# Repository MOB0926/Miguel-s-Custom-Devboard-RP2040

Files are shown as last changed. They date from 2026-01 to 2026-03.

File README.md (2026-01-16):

# Miguel-s-Custom-Devboard-RP2040
I started this project as a way to practice and learn some more about pcb design. This board is not perfect as it is my second pcb and my first devboard.
    
# Schematic Design
    
I followed the [Custom Devboard Guided Project](https://blueprint.hackclub.com/starter-projects/devboard) by [Kai Pereira](https://github.com/KaiPereira/build-a-devboard) so it was not my design but I did rout the PCB myself an added and LED.
     
The designs and components are directly from the guide but the LED I added once I realized how empty the board was at the pcb design section.
    
Components:
- RP 2040
- LED (SK6812-mini-e)   This is not in KICAD lib, I had to use [Master Lib](https://github.com/ebastler/marbastlib)
- USB-C-2.0
- Voltage regulator (MCP1700T-3302E/TT)
- Crystal Ocilater (12mhz)
- I/O (1x20)x2 (1x3)x1
- Flash Memory/Storage (W25Q16JVZPIQ) (16-Mbi)
     

     
# PCB Design
     
The board dimensions and I/O location are exact from the guide but the rest I ended up moving around to fit my routing. The LED I placed in the very empty bottom of the board above the 1x3 pins.
         
I routed the USB first then the Flash, followed by the crystal ocilator. Once the important connections were made I connected the I/O and LED, lastly I set up the ground pour and fixed any errors the ERC flaged.
         

      

       
# Prep For Manufacturing
         
Once I was sure I had finished the board I downloaded the necessary design files from KICAD (.gbr , BOM , CPL) I edited the BOM and CPL formats to fit JLCPCB and uploaded my design.
      
Once the files were uploaded, I chose the correct settings for my design and whent on to choosing what parts JLCPCB would buy and install for me.
          
ALL basic components I selected and most Extended components as they are far to complicated to solder myself but the I/O pins and LED I will add myself to save A LOT of money. (Almost 30 dollars)
      
I actually made an error originaly where my board was set up as "Standard PCBA" not "Economic PCBA" which is why I had to place the LED myself and why I saved $30.
        

         

          

           

          
# V1 vs V2
          
Honestly they are not too different but V2 was a complete restart for the pcb routing and component placement as V1 was full of errors that were easier to re-do than fix.
       
# BOM
    
- PCB ~ $39.36 [JLCPCB](https://jlcpcb.com/) (For 5 pcbs / 2 pcba)
- I/O Pins ~ $1.26 + Shipping [AliExpress](https://www.aliexpress.us/item/3256805070463808.html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) (For 10 1x40 Breakeable 2.54mm Male Pins)
- LED (SK6812mini-e)(3mA) ~ $3.51 + Shipping [AliExpress]([https://www.aliexpress.us/item/3256806781745425.html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](https://www.aliexpress.us/item/3256807677321116.html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)) (For 100) (Only need one but this is cheaper because of choice shipping than getting a 10pc)
- Total ~ $47
    
# THE END
     
So yeah thats it really
    
I spent about 19-20 hours on this. I learnt A LOT about Schematic/PCB design on KICAD specificaly. I also learnt how to get a project to manufacturing (Which I cant wait to get my first Devboard design to play with)
     
I do not plan to return to this project, I will probably at some point in the near future make another board but with a more specific use and maybe a diferent MCU so I can get more experience

# Thanks

- Myself (For all the time I put into this)
- [Kai Pereira](https://kaipereira.com/) (For the Guide)
- [HackClub](https://hackclub.com/) / [Blueprint](https://blueprint.hackclub.com/home) (For the opportunity to do a project like this)
- You (For reading this)

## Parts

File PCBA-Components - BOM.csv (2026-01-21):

Comment | Designator | Footprint | JLCPCB Part #
330 | R8 | R_0402_1005Metric | C25104
1uF | C1,C10 | C_0402_1005Metric | C52923
MCP1700x-330xxTT | U2 | SOT-23 | C39051
33pF | C15,C16 | C_0402_1005Metric | C1562
1K | R6,R5 | R_0402_1005Metric | C11702
5.1K | R1,R2 | R_0402_1005Metric | C25905
12MHz | Y1 | Crystal_SMD_3225-4Pin_3.2x2.5mm | C9002
10uF | C14,C13 | C_0603_1608Metric | C19702
RP2040 | U1 | QFN-56-1EP_7x7mm_P0.4mm_EP3.2x3.2mm | C2040
0.1uF | C17,C7,C8,C2,C12,C9,C11,C5,C3,C4,C6,C18 | C_0402_1005Metric | C1525
W25Q16JVZPIQTR | U3 | Winbond_USON-8-1EP_3x2mm_P0.5mm_EP0.2x1.6mm | C2843335
10K | R7 | R_0402_1005Metric | C25744
USB_C_Receptacle_USB2.0_14P | J1 | USB_C_Receptacle_HRO_TYPE-C-31-M-12 | C165948
27 | R3,R4 | R_0402_1005Metric | C25100
SW_Push | SW1 | SW_Push_SPST_NO_Alps_SKRK | C720477

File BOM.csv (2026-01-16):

Item | Price (incl: shipping) | Qty | Vendor
PCB | $4 | x5 | JLCPCB
PCBA | $35.36 | x2 | JLCPCB
SK6812mini-e | $4.51 | x100 | AliExpress
01x40 Pin Headers | $2.26 | x10 | AliExpress
Total | $46.13

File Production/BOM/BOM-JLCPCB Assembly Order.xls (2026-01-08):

JLCPCB BOM Tool - BOM Matching
BOM name：BOM-JLCPCB Assembly Order.xlsx |  |  | Download Time：2026-01-08 03:55:06 |  |  |  | * Our matching results are updated in real-time, but stock and prices may change. If it's been over 24 hours, please re-match before placing your order.
PCB Assembled Qty：5 |  |  | Est. Total Price：13.4184
Your BOM |  |  |  |  | Matched Parts |  |  |  |  |  |  | Order Information
Top Designator | Bottom Designator | Comment | Footprint | JLCPCB Part # | Matches | Part # | Manufacturer | Footprint | Description | Category | Warning | JLCPCB Part # | Product link | Lib Type | Qty | Source | Total Price ($)
C1,C10 |  | 1uF | C_0402_1005Metric |  | Select by Customer | CL05A105KA5NQNC | Samsung Electro-Mechanics | 0402 | 1uF 25V X5R ±10% 0402 Multilayer Ceramic Capacitors MLCC - SMD/SMT ROHS | Multilayer Ceramic Capacitors MLCC - SMD/SMT |  | C52923 | https://jlcpcb.com/partdetail/53938-CL05A105KA5NQNC/C52923 | Basic | 20 | 20 JLCPCB | 0.06
C14,C13 |  | 10uF | C_0603_1608Metric |  | Select by Customer | CL10A106KP8NNNC | Samsung Electro-Mechanics | 0603 | 10V 10uF X5R ±10% 0603 Multilayer Ceramic Capacitors MLCC - SMD/SMT ROHS | Multilayer Ceramic Capacitors MLCC - SMD/SMT |  | C19702 | https://jlcpcb.com/partdetail/20411-CL10A106KP8NNNC/C19702 | Basic | 20 | 20 JLCPCB | 0.116
C15,C16 |  | 33pF | C_0402_1005Metric |  | Select by Customer | 0402CG330J500NT | FH (Guangdong Fenghua Advanced Tech) | 0402 | 33pF 50V C0G ±5% 0402 Multilayer Ceramic Capacitors MLCC - SMD/SMT ROHS | Multilayer Ceramic Capacitors MLCC - SMD/SMT |  | C1562 | https://jlcpcb.com/partdetail/1914-0402CG330J500NT/C1562 | Basic | 20 | 20 JLCPCB | 0.022
C17,C7,C8,C2,C12,C9,C11,C5,C3,C4,C6,C18 |  | 0.1uF | C_0402_1005Metric |  | Select by Customer | CL05B104KO5NNNC | Samsung Electro-Mechanics | 0402 | 100nF 16V X7R ±10% 0402 Multilayer Ceramic Capacitors MLCC - SMD/SMT ROHS | Multilayer Ceramic Capacitors MLCC - SMD/SMT | 1.The comment (CL05B104KO5NNNC) of this part does not match the one (0.1uF) provided in your BOM. Please confirm; | C1525 | https://jlcpcb.com/partdetail/1877-CL05B104KO5NNNC/C1525 | Basic | 70 | 70 JLCPCB | 0.084
J1 |  | USB_C_Receptacle_USB2.0_14P | USB_C_Receptacle_HRO_TYPE-C-31-M-12 |  | Select by Customer | TYPE-C-31-M-12 | Korean Hroparts Elec | SMD | -30℃~+80℃ 1 10,000 cycles 16P 20V 5A 7.35mm Female Surface Mount, Right Angle Type-C SMD USB Connectors ROHS | USB Connectors |  | C165948 | https://jlcpcb.com/partdetail/Korean_HropartsElec-TYPE_C_31_M12/C165948 | Extended | 5 | 5 JLCPCB | 0.8825
J3,J2 |  | Conn_01x20 | PinHeader_1x20_P2.54mm_Vertical |  | Select by Customer | KH-1.27PH180-1X20P-L7.2 | Shenzhen Kinghelm Elec | 插件,P=1.27mm | -40℃~+105℃ 1 1.27mm 1A 1mm 1x20P 2.3mm 20P 3.9mm Pin Header Through Hole Plugin,P=1.27mm Pin Headers ROHS | Pin Headers |  | C2938409 | https://jlcpcb.com/partdetail/3294789-KH_1_27PH180_1X20P_L72/C2938409 | Extended | 0 | 0 JLCPCB | 0
J4 |  | Conn_01x03 | PinHeader_1x03_P2.54mm_Vertical |  | Select by Customer | 2.54-1*3P针 | BOOMELE(Boom Precision Elec) | 插件,P=2.54mm | -40℃~+105℃ 1 1x3P 2.54mm 2.5mm 3A 3P 3mm 6mm Black Brass Gold Pin Header Through Hole Plugin,P=2.54mm Pin Headers ROHS | Pin Headers |  | C49257 | https://jlcpcb.com/partdetail/50265-2_54_1_3P/C49257 | Extended | 0 | 0 JLCPCB | 0
LED1 |  | SK6812MINI-E | LED_6028R |  | Select by Customer | SK6812MINI-E | OPSCO Optoelectronics | SMD | -40℃~+85℃ 0.6mA 1.78mm 120° 1kHz 2.8mm 2000V 3.2mm 3.7V~5.5V 800Kbit/s G:815mcd~1275mcd R:620nm~625nm Semi-transparent lens SMD RGB LEDs(Built-in IC) ROHS | RGB LEDs(Built-In IC) |  | C5149201 | https://jlcpcb.com/partdetail/OPSCOOptoelectronics-SK6812MINIE/C5149201 | Extended | 7 | 7 JLCPCB | 0.6034
R1,R2 |  | 5.1K | R_0402_1005Metric |  | Select by Customer | 0402WGF5101TCE | UNI-ROYAL(Uniroyal Elec) | 0402 | -55℃~+155℃ 5.1kΩ 50V 62.5mW Thick Film Resistor ±1% ±100ppm/℃ 0402 Chip Resistor - Surface Mount ROHS | Chip Resistor - Surface Mount |  | C25905 | https://jlcpcb.com/partdetail/26648-0402WGF5101TCE/C25905 | Basic | 20 | 20 JLCPCB | 0.012
R3,R4 |  | 27 | R_0402_1005Metric |  | Select by Customer | 0402WGF270JTCE | UNI-ROYAL(Uniroyal Elec) | 0402 | -55℃~+155℃ 27Ω 50V 62.5mW Thick Film Resistor ±1% ±100ppm/℃ 0402 Chip Resistor - Surface Mount ROHS | Chip Resistor - Surface Mount | 1.The comment (0402WGF270JTCE) of this part does not match the one (27) provided in your BOM. Please confirm; | C25100 | https://jlcpcb.com/partdetail/25843-0402WGF270JTCE/C25100 | Extended | 22 | 22 JLCPCB | 0.0132
R6,R5 |  | 1K | R_0402_1005Metric |  | Select by Customer | 0402WGF1001TCE | UNI-ROYAL(Uniroyal Elec) | 0402 | -55℃~+155℃ 1kΩ 50V 62.5mW Thick Film Resistor ±1% ±100ppm/℃ 0402 Chip Resistor - Surface Mount ROHS | Chip Resistor - Surface Mount | 1.The comment (0402WGF1001TCE) of this part does not match the one (1K) provided in your BOM. Please confirm; | C11702 | https://jlcpcb.com/partdetail/12256-0402WGF1001TCE/C11702 | Basic | 20 | 20 JLCPCB | 0.012
R7 |  | 10K | R_0402_1005Metric |  | Select by Customer | 0402WGF1002TCE | UNI-ROYAL(Uniroyal Elec) | 0402 | -55℃~+155℃ 10kΩ 50V 62.5mW Thick Film Resistor ±1% ±100ppm/℃ 0402 Chip Resistor - Surface Mount ROHS | Chip Resistor - Surface Mount | 1.The comment (0402WGF1002TCE) of this part does not match the one (10K) provided in your BOM. Please confirm; | C25744 | https://jlcpcb.com/partdetail/26487-0402WGF1002TCE/C25744 | Basic | 20 | 20 JLCPCB | 0.012
R8 |  | 330 | R_0402_1005Metric |  | Select by Customer | 0402WGF3300TCE | UNI-ROYAL(Uniroyal Elec) | 0402 | -55℃~+155℃ 330Ω 50V 62.5mW Thick Film Resistor ±1% ±100ppm/℃ 0402 Chip Resistor - Surface Mount ROHS | Chip Resistor - Surface Mount | 1.The comment (0402WGF3300TCE) of this part does not match the one (330) provided in your BOM. Please confirm; | C25104 | https://jlcpcb.com/partdetail/25847-0402WGF3300TCE/C25104 | Basic | 20 | 20 JLCPCB | 0.014
SW1 |  | SW_Push | SW_Push_SPST_NO_Alps_SKRK |  | Select by Customer | TS-1088-AR02016 | XUNPU | SMD,4x3mm | -30℃~+80℃ 1.6N 100,000 Cycles 12V 2mm 3mm 4mm 50mA Black Round Button SMD(SMT) Tab SPST Surface Mount,Vertical Without Bracket SMD,4x3mm Tactile Switches ROHS | Tactile Switches |  | C720477 | https://jlcpcb.com/partdetail/XUNPU-TS_1088AR02016/C720477 | Basic | 9 | 9 JLCPCB | 0.3987
U1 |  | RP2040 | QFN-56-1EP_7x7mm_P0.4mm_EP3.2x3.2mm |  | Select by Customer | RP2040 | Raspberry Pi | LQFN-56(7x7) | 12bit 133MHz 30 LQFN-56(7x7) Microcontrollers (MCU/MPU/SOC) ROHS | Microcontrollers (MCU/MPU/SOC) |  | C2040 | https://jlcpcb.com/partdetail/RaspberryPi-RP2040/C2040 | Extended | 5 | 5 JLCPCB | 4.7745
U2 |  | MCP1700x-330xxTT | SOT-23 |  | Select by Customer | MCP1700T-3302E/TT | Microchip Tech | SOT-23 | -40℃~+125℃@(Tj) 1 1.6uA 178mV@(250mA) 250mA 3.3V 44dB@(100Hz) 6V Fixed Over Temperature Protection Positive SOT-23 Voltage Regulators - Linear, Low Drop Out (LDO) Regulators ROHS | Voltage Regulators - Linear, Low Drop Out (LDO) Regulators |  | C39051 | https://jlcpcb.com/partdetail/MicrochipTech-MCP1700T_3302ETT/C39051 | Extended | 5 | 5 JLCPCB | 1.7865
U3 |  | W25Q16JVZPIQTR | Winbond_USON-8-1EP_3x2mm_P0.5mm_EP0.2x1.6mm |  | Select by Customer | W25Q16JVUXIQ | Winbond Elec | USON-8-EP(2x3) | -40℃~+85℃ 100,000 Cycles 10uA 133MHz 16Mbit 2.7V~3.6V 20 Years 3ms SPI USON-8-EP(2x3) NOR FLASH ROHS | NOR FLASH | 1.The comment (W25Q16JVUXIQ) of this part does not match the one (W25Q16JVZPIQTR) provided in your BOM. Please confirm; | C2843335 | https://jlcpcb.com/partdetail/WinbondElec-W25Q16JVUXIQ/C2843335 | Extended | 5 | 5 JLCPCB | 4.0165
Y1 |  | 12MHz | Crystal_SMD_3225-4Pin_3.2x2.5mm |  | Select by Customer | X322512MSB4SI | YXC Crystal Oscillators | SMD3225-4P | -40℃~+85℃ 12MHz 20pF Crystal Oscillator ±10ppm ±20ppm SMD3225-4P Crystals ROHS | Crystals |  | C9002 | https://jlcpcb.com/partdetail/YXC_CrystalOscillators-X322512MSB4SI/C9002 | Basic | 9 | 9 JLCPCB | 0.6111

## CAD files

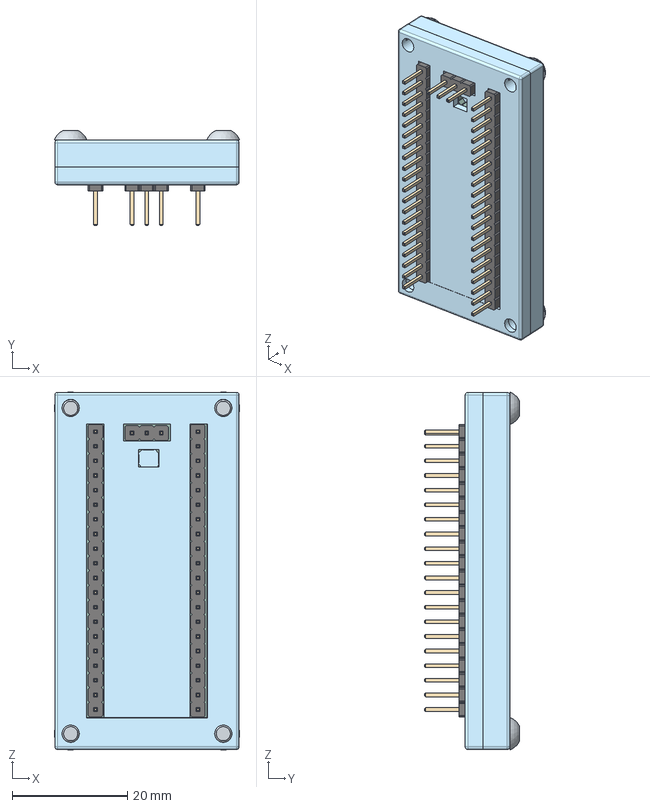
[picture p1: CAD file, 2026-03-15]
3D-Render/3D-Model.step
32.2 x 16.5 x 62.2 mm
R_0402_1005Metric_3
C_0402_1005Metric_11
PinHeader_1x20_P2.54mm_Vertical_1
C_0402_1005Metric_10
R_0402_1005Metric_1
C_0402_1005Metric_9
C_0402_1005Metric_5
C_0402_1005Metric_12
PinHeader_1x20_P2.54mm_Vertical
Crystal_SMD_3225-4Pin_3.2x2.5mm
QFN-56-1EP_7x7mm_P0.4mm_EP3.2x3.2mm
C_0603_1608Metric
R_0402_1005Metric_2
R_0402_1005Metric_7
Winbond_USON-8-1EP_3x2mm_P0.5mm_EP0.2x1.6mm
R_0402_1005Metric
SOT-23
C_0402_1005Metric_14
C_0402_1005Metric_1
PinHeader_1x03_P2.54mm_Vertical
Socket button head screw M3x0.5 x 5 x 4
C_0402_1005Metric_6
C_0402_1005Metric_7
C_0402_1005Metric_4
C_0402_1005Metric_15
C_0402_1005Metric_8
C_0402_1005Metric_13
C_0603_1608Metric_1
SW_Push_SPST_NO_Alps_SKRK
C_0402_1005Metric
R_0402_1005Metric_6
R_0402_1005Metric_4
C_0402_1005Metric_2
C_0402_1005Metric_3
R_0402_1005Metric_5

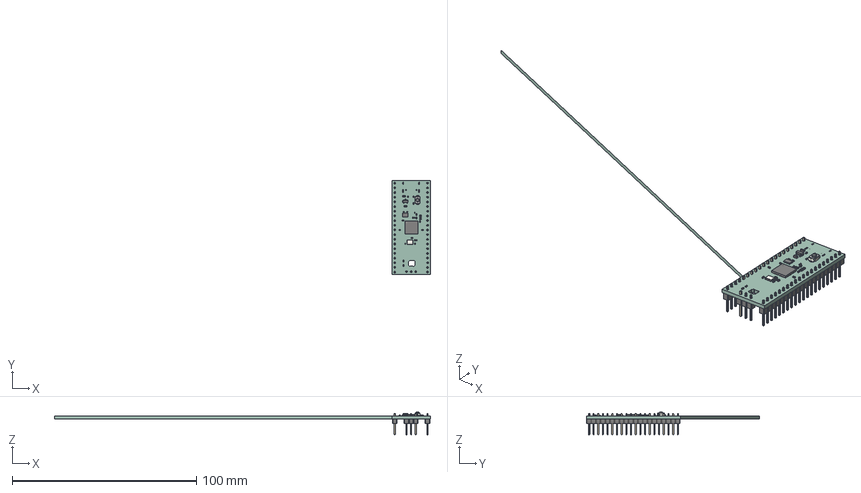
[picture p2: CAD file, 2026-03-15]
PCB/PCB-V2/Miguel's-Custom-Devboard - V2.step
204.0 x 94.0 x 12.2 mm
C_0402_1005Metric x 16
R_0402_1005Metric x 8
QFN-56-1EP_7x7mm_P0.4mm_EP3.2x3.2mm
C_0603_1608Metric x 2
Crystal_SMD_3225-4Pin_3.2x2.5mm
SOT-23
SW_Push_SPST_NO_Alps_SKRK
Winbond_USON-8-1EP_3x2mm_P0.5mm_EP0.2x1.6mm
PinHeader_1x03_P2.54mm_Vertical
PinHeader_1x20_P2.54mm_Vertical x 2
Miguel's-Custom-Devboard - V2_PCB

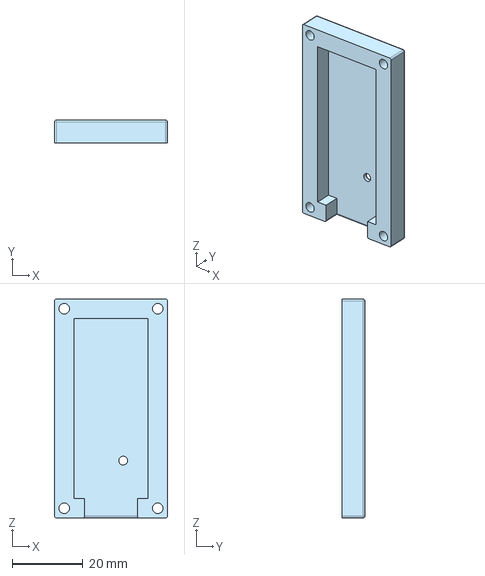
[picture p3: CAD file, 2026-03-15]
3D-Render/Case-Top.step
32.0 x 6.50 x 62.0 mm

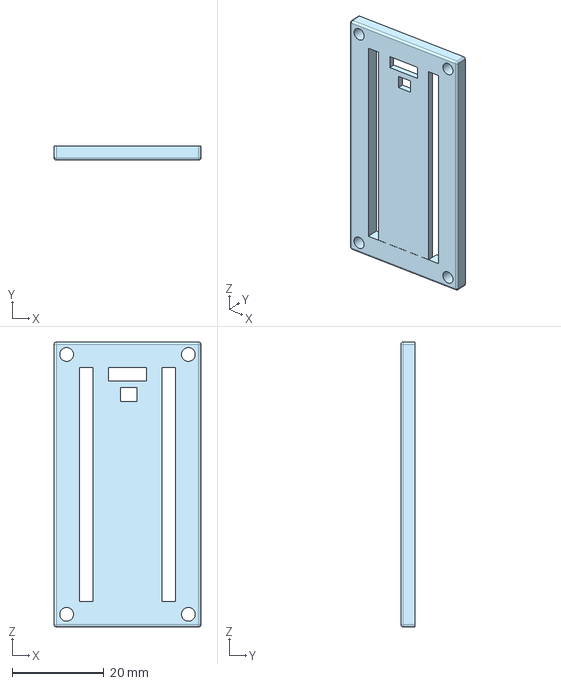
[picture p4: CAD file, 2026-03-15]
3D-Render/Case-Bottom.step
32.0 x 3.10 x 62.0 mm

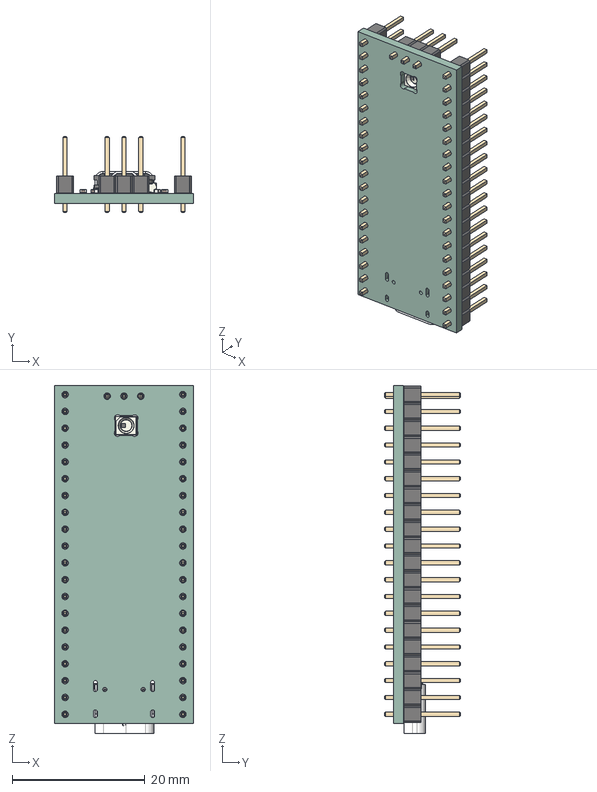
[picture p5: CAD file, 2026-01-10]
3D-Render/Miguel's-Custom-Devboard-RP-2040-3D-Render.step
21.0 x 11.5 x 52.5 mm
USB_type_C_6p x 4
QFN-56-1EP_7x7mm_P0.4mm_EP3.2x3.2mm
R_0402_1005Metric x 8
C_0603_1608Metric x 2
LED_SK6812MINI-E x 5
PinHeader_1x20_P2.54mm_Vertical x 2
C_0402_1005Metric x 16
PinHeader_1x03_P2.54mm_Vertical
Crystal_SMD_3225-4Pin_3.2x2.5mm
Winbond_USON-8-1EP_3x2mm_P0.5mm_EP0.2x1.6mm
SW_Push_SPST_NO_Alps_SKRK
SOT-23

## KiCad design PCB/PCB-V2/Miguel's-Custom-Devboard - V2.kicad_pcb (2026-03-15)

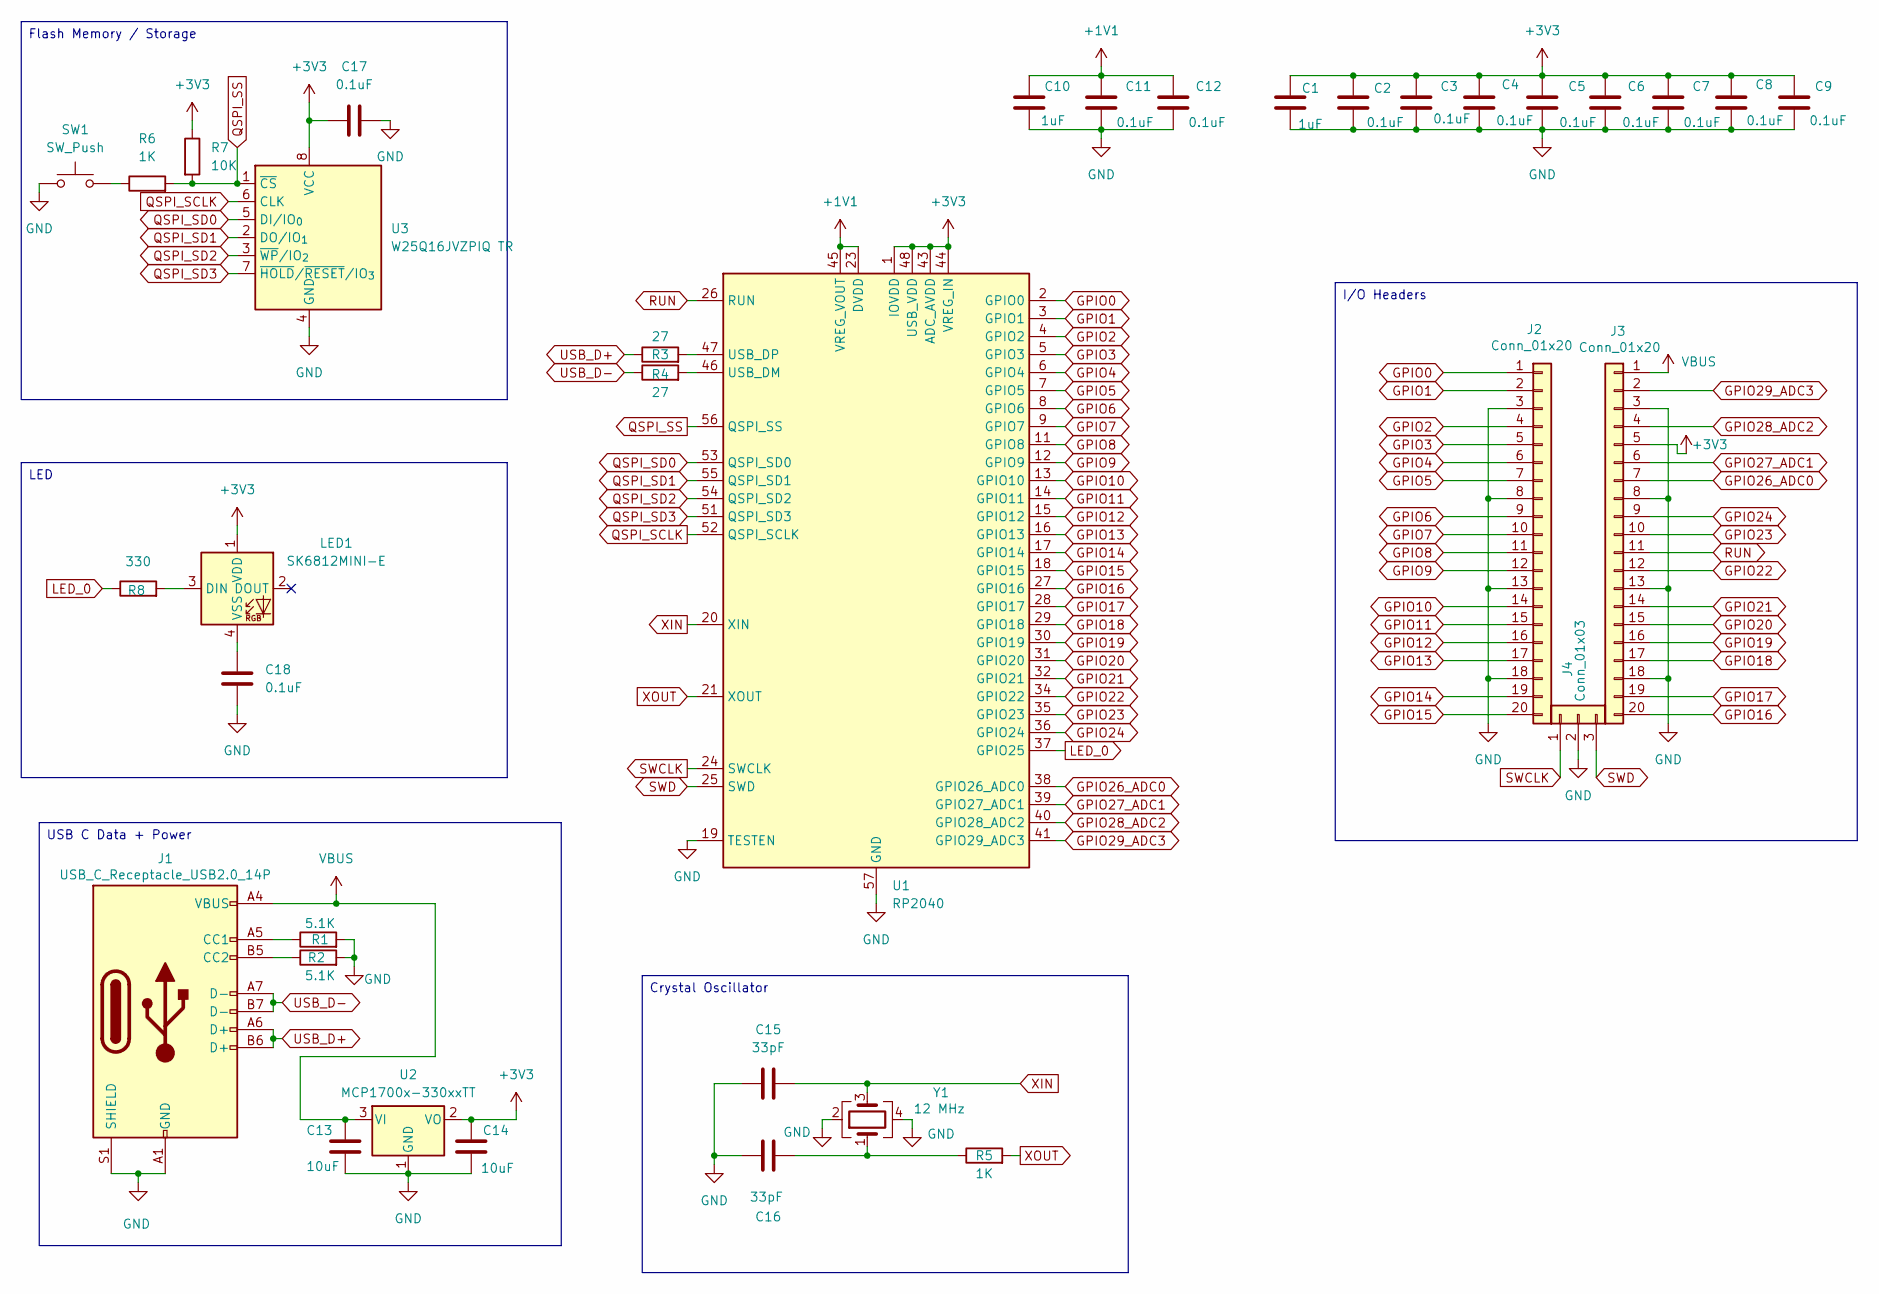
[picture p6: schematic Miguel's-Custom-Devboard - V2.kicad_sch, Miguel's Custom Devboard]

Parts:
C1, C10: 1uF; C_0402_1005Metric
C2, C3, C4, C5, C6, C7, C8, C9, C11, C12, C17, C18: 0.1uF; C_0402_1005Metric
C13, C14: 10uF; C_0603_1608Metric
C15, C16: 33pF; C_0402_1005Metric
J1: USB_C_Receptacle_USB2.0_14P; USB_C_Receptacle_HRO_TYPE-C-31-M-12
J2, J3: Conn_01x20; PinHeader_1x20_P2.54mm_Vertical
J4: Conn_01x03; PinHeader_1x03_P2.54mm_Vertical
LED1: SK6812MINI-E; LED_6028R
R1, R2: 5.1K; R_0402_1005Metric
R3, R4: 27; R_0402_1005Metric
R5, R6: 1K; R_0402_1005Metric
R7: 10K; R_0402_1005Metric
R8: 330; R_0402_1005Metric
SW1: SW_Push; SW_Push_SPST_NO_Alps_SKRK
U1: RP2040; QFN-56-1EP_7x7mm_P0.4mm_EP3.2x3.2mm
U2: MCP1700x-330xxTT; SOT-23
U3: W25Q16JVZPIQ TR; Winbond_USON-8-1EP_3x2mm_P0.5mm_EP0.2x1.6mm
Y1: 12 MHz; Crystal_SMD_3225-4Pin_3.2x2.5mm

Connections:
+1V1: C10.1, C11.1, C12.1, U1.23 (DVDD), U1.45 (VREG_VOUT), U1.50 (DVDD)
+3V3: C1.1, C2.1, C3.1, C4.1, C5.1, C6.1, C7.1, C8.1, C9.1, C14.1, C17.1, J3.5, LED1.1 (VDD), R7.1, U1.1 (IOVDD), U1.10 (IOVDD), U1.22 (IOVDD), U1.33 (IOVDD), U1.42 (IOVDD), U1.43 (ADC_AVDD), U1.44 (VREG_IN), U1.48 (USB_VDD), U1.49 (IOVDD), U2.2 (VO), U3.8 (VCC)
GND: C1.2, C2.2, C3.2, C4.2, C5.2, C6.2, C7.2, C8.2, C9.2, C10.2, C11.2, C12.2, C13.2, C14.2, C15.1, C16.1, C17.2, C18.2, J1.A1 (GND), J1.A12 (GND), J1.B1 (GND), J1.B12 (GND), J1.S1 (SHIELD), J2.3, J2.8, J2.13, J2.18, J3.3, J3.8, J3.13, J3.18, J4.2, R1.2, R2.2, SW1.1, U1.19 (TESTEN), U1.57 (GND), U2.1 (GND), U3.4 (GND), Y1.2, Y1.4
GPIO0: J2.1, U1.2 (GPIO0)
GPIO1: J2.2, U1.3 (GPIO1)
GPIO2: J2.4, U1.4 (GPIO2)
GPIO3: J2.5, U1.5 (GPIO3)
GPIO4: J2.6, U1.6 (GPIO4)
GPIO5: J2.7, U1.7 (GPIO5)
GPIO6: J2.9, U1.8 (GPIO6)
GPIO7: J2.10, U1.9 (GPIO7)
GPIO8: J2.11, U1.11 (GPIO8)
GPIO9: J2.12, U1.12 (GPIO9)
GPIO10: J2.14, U1.13 (GPIO10)
GPIO11: J2.15, U1.14 (GPIO11)
GPIO12: J2.16, U1.15 (GPIO12)
GPIO13: J2.17, U1.16 (GPIO13)
GPIO14: J2.19, U1.17 (GPIO14)
GPIO15: J2.20, U1.18 (GPIO15)
GPIO16: J3.20, U1.27 (GPIO16)
GPIO17: J3.19, U1.28 (GPIO17)
GPIO18: J3.17, U1.29 (GPIO18)
GPIO19: J3.16, U1.30 (GPIO19)
GPIO20: J3.15, U1.31 (GPIO20)
GPIO21: J3.14, U1.32 (GPIO21)
GPIO22: J3.12, U1.34 (GPIO22)
GPIO23: J3.10, U1.35 (GPIO23)
GPIO24: J3.9, U1.36 (GPIO24)
GPIO26_ADC0: J3.7, U1.38 (GPIO26_ADC0)
GPIO27_ADC1: J3.6, U1.39 (GPIO27_ADC1)
GPIO28_ADC2: J3.4, U1.40 (GPIO28_ADC2)
GPIO29_ADC3: J3.2, U1.41 (GPIO29_ADC3)
LED_0: R8.1, U1.37 (GPIO25)
unnamed: C16.2, R5.1, Y1.1
unnamed: J1.A5 (CC1), R1.1
unnamed: J1.B5 (CC2), R2.1
unnamed: LED1.3 (DIN), R8.2
unnamed: C18.1, LED1.4 (VSS)
unnamed: R6.1, SW1.2
unnamed: R4.2, U1.46 (USB_DM)
unnamed: R3.2, U1.47 (USB_DP)
QSPI_SCLK: U1.52 (QSPI_SCLK), U3.6 (CLK)
QSPI_SD0: U1.53 (QSPI_SD0), U3.5 (DI/IO_{0})
QSPI_SD1: U1.55 (QSPI_SD1), U3.2 (DO/IO_{1})
QSPI_SD2: U1.54 (QSPI_SD2), U3.3 (~WP/IO_{2})
QSPI_SD3: U1.51 (QSPI_SD3), U3.7 (~HOLD/~RESET/IO_{3})
QSPI_SS: R6.2, R7.2, U1.56 (QSPI_SS), U3.1 (~CS)
RUN: J3.11, U1.26 (RUN)
SWCLK: J4.1, U1.24 (SWCLK)
SWD: J4.3, U1.25 (SWD)
USB_D+: J1.A6 (D+), J1.B6 (D+), R3.1
USB_D-: J1.A7 (D-), J1.B7 (D-), R4.1
VBUS: C13.1, J1.A4 (VBUS), J1.A9 (VBUS), J1.B4 (VBUS), J1.B9 (VBUS), J3.1, U2.3 (VI)
XIN: C15.2, U1.20 (XIN), Y1.3
XOUT: R5.2, U1.21 (XOUT)

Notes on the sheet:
Crystal Oscillator
Flash Memory / Storage
I/O Headers
USB C Data + Power
LED

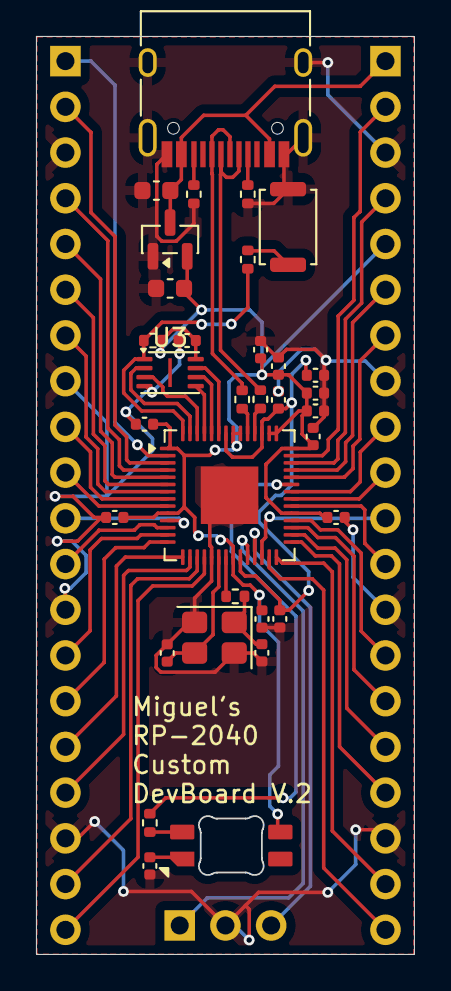
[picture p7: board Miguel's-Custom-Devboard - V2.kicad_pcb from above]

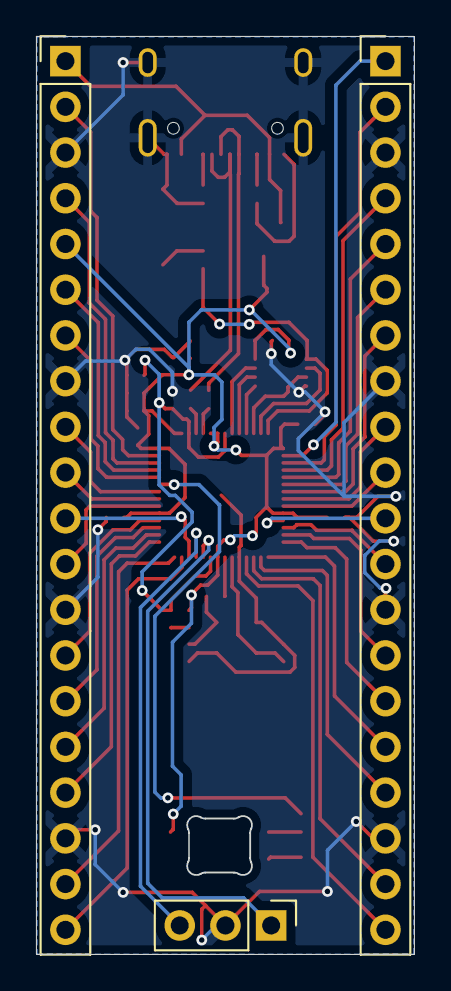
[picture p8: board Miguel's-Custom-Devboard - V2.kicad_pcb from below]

Board: 2 copper layers, 21.0 x 51.0 mm, 36 parts (3 on the bottom side), 55 nets.

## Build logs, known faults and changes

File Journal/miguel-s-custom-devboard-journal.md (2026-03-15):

<!--
  This journal is auto generated by Hack Club Blueprint.
-->

# 12/29/2025 - Created Schematic  

_Time spent: 3.5h_  

I created a File for my project and added a PCB file inside where I will be housing my KiCad files for the project.

I then began to add my components into my schematic. For this I followed the guide on what I needed and how I connected it all. 

Components: 
- RP2040 (MCU)
- Crystal Oscillator (Clock Basicaly)
- Flash Memory (Memory / Storage)
- I/O Headers
- USB_C (For power and data)

After I added everything I ran an ERC (Electrical Rules Check) to make sure there were no errors I did not notice.

imagen

# 12/30/2025 12 AM - Laying out the PCB  

_Time spent: 4.5h_  

Assigned the correct footprints for the components in the schematic footprint editor.

Once the schematic was done I got started on the PCB.

I set the large components in place and most of the capacitors. I then began to rout the high speed connections to get an idea of where to place all other connections.

(I am in PCB hell with these capacitors)

After the highspeed was done I began to connect the capacitors and GPIO pins.

I now must sleep so the rest of the PCB will have to be completed tomorrow.

imagen

# 12/30/2025 4 PM - Continued Routing PCB + Added LED  

_Time spent: 1.5h_  

Finished routing GPIO and noticed the GPIO 25 was unused, so I added an addressable LED (SK6812 Mini)

After that I contiued with the ground but im out of time so I will finish it later.

imagen

imagen

# 12/31/2025 - Finished Routing  

_Time spent: 0.5h_  

I finaly finished all of the unfinished traces, and I technicaly finished my PCB but it has a lot of DRC errors and warnings.

I think the board is very ineficient since it is my first attemt at such a complicated build, so I am tempted to give the PCB a second run now that I am more experienced.

imagen

imagen

# 1/3/2026 - V.2 of PCB  

_Time spent: 3.0h_  

Well I completetly re-routed the PCB in a V.2 doc to fix all of the errors and ineficiensies without completely erasing my work.

This took much longer than it should have but i have been traveling a lot and made the error of not constantly saving a few times.

I also removed most of the silkscreen as it was getting out of hand





# 1/8/2026 5:04 PM - Prepared for Possible Production  

_Time spent: 5.0h_  

I prepared my design for manufacturing in JLCPCB

This took a long time because it is the first time I do this and once I was almost done I realized the LED I had chosen was unavailable and had to choose another one, which meant going back to the schematic and pcb and completely redoing the prep for manufacturing.
   

   

   

   

(WOW THIS IS EXPENSIVE) (Definitely going to have to remove some things to solder myself)  

# 1/8/2026 5:18 PM - A.I. strikes again  

_Time spent: 0.1h_  

I removed any part I had any skill to solder myself but I would only really save like max 8 dollars which is definitely less than what it would cost to buy these components myself plus the risk of damaging anything
   
I guess this one will have to wait due to the A.I. ram/memory crisis making my flash memory cost 4x what it should
   
  

# 1/8/2026 5:34 PM - It was not A.I.  

_Time spent: 0.1h_  

BOOOOOM Figured it out.
I stuck my two braincells together and realized I had it a Standard PCBA not Economic

Changing it cause a slight problem where it would deny me the ability to use economic due to my led but by changing it to a different version and then deselecting it I have succeded in saving myself 30 dollars


  

    


# 1/9/2026 9 PM - Created Repo  

_Time spent: 1.0h_  

I uploaded my design files and jurnal to my repo, and created a readme where I added information and pictures of my work and journey through this project.



# 1/9/2026 10 PM - Finalized Repo + Product Shipped  

_Time spent: 1.0h_  

I checked the guidelines and am pretty sure my project is ready for submission. I completed my repo and finished my BOM

I have now sent my project in for review (I hope I didn't forget anything dumb)





# 1/14/2026 - Updated BOM  

_Time spent: 0.1h_  

Hehehe I forgot to change to only 2 pcba, I never did because JLCPCB was not allowing me to select it in the cart but after some research I just had to go back to edit the pcb settings so I got that resolved

Also my BOM was a little inaccurate so I updated that to reflect the changes





# 1/20/2026 - PCBA - BOM  

_Time spent: 0.1h_  

Added CSV file to Repository containing my PCBA bill of materials from JLCPCB. Whats not included there are the LED and GPIO headers but that's because that I will add myself.

(Ill also add pictures here if that's easier.)



# 1/22/2026 - Grant Approved / Everything Ordered  

_Time spent: 0.5h_  

Got my grant approved a little earlier today, so i have now ordered everything and will be able to get to work in a very long time. (This will actually take like 2-3 weeks so do not expect updates ANY time soon)



  

# 2/11/2026 - Made A Case  

_Time spent: 3.0h_  

I have the boards as of a week or two ago. 

I'm still waiting for the AliExpress order so I made a little case to keep my project safe while I wait.



I made the case for M3 by 5 bolts but they looked monstrous in the CAD so I swapped to M2 for the picture. I only have M3 so i will just have to live with the awkward proportions. 

I'll probably come back to this and make it larger to better fit the M3 bolts but that will be later because I'm tired.

# 3/14/2026 - Done  

_Time spent: 5.0h_  

**Done!!!**

I have received everything and soldered everything together.


(Don't have a picture of the PCB fully soldered outside of the case but just imagine this image with pins instead of holes.)

I had to re print my case a few times because I kept messing up the USB slot size but today I finally printed one that works.


(Failed case prints + Final Product)

I have moderately tested my design by flashing it with CircuitPython and running an LED flashing script but I will try some more GPIO mini projects to show off in my Demo.

**What's next?**

I will review my Repo and update all of my files before submitting my design.

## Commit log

2026-01-08 LED Change (Files Updated)
    [BOM-JLCPCB Assembly Order.xls, BOM.csv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]
2026-01-10 Remove duplicate LED entry from BOM section
2026-01-15 Update BOM pricing and links in README.md
2026-01-15 Revise BOM prices and links for components
    Updated prices and links for I/O Pins and LED components in the BOM section.
2026-01-16 Update PCBA price and total in BOM.csv
    [BOM.csv]
2026-03-15 Final Update
    [3D-Model.step, Case-Bottom.step, Case-Top.step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]
